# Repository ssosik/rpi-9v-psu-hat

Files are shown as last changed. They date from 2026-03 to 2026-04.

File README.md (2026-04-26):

# Raspberry Pi Preamp PSU HAT — Rev 3

A KiCad-designed Raspberry Pi HAT that generates a clean, isolated +9V supply from the Pi's 5V GPIO rail, intended to power low-noise electret microphone preamplifier circuits (such as the [ESP P93](https://sound-au.com/project93.htm)) for field audio recording applications like [BirdNET-Pi](https://github.com/mcguirepr89/BirdNET-Pi).

## Schematic

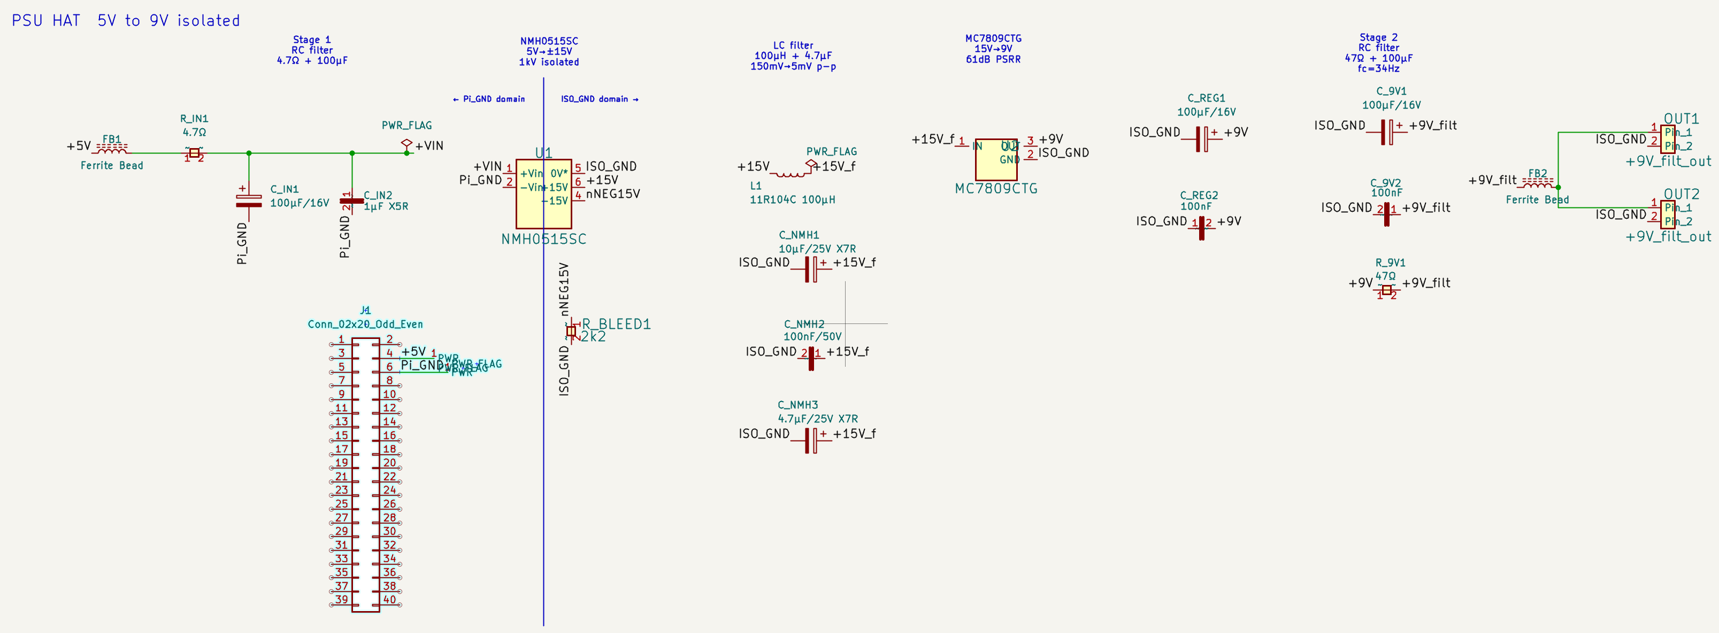
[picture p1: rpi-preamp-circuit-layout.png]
Schematic


## PCB Layout

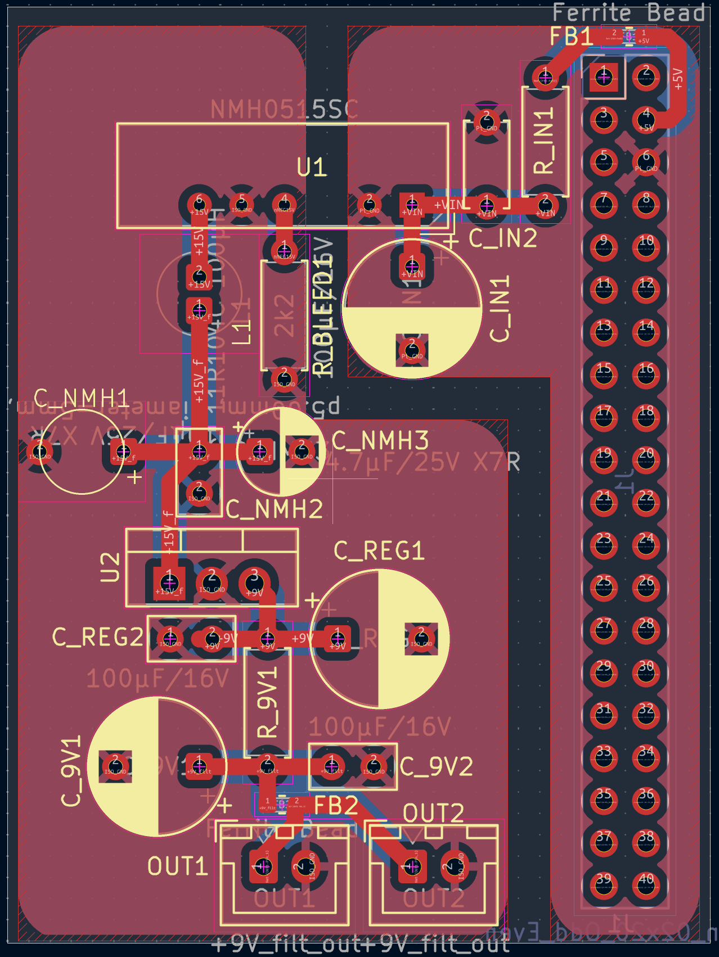
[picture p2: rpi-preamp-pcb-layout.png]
PCB Layout


## Overview

The Pi's 5V supply rail is noisy — unsuitable for sensitive microphone preamp circuits without significant filtering and regulation. This HAT addresses that with a multi-stage power supply chain:

1. **Stage 1 — Input filter**: Ferrite bead + capacitors attenuate high-frequency noise on the 5V input
2. **Isolated DC-DC conversion**: NMH0515SC converts 5V to ±15V with galvanic isolation, breaking any ground-loop path between the Pi and the preamp
3. **LC filter**: 100µH inductor + capacitors reduce switching noise from the DC-DC converter
4. **Linear regulation**: MC7809CTG drops the rectified +15V to a clean, regulated +9V
5. **Stage 2 — Output filter**: 47Ω series resistor + ferrite bead + multi-stage capacitor bank (100µF + 100nF) attenuates residual ripple before the output connectors

Two JST XH 2-pin output connectors (OUT1, OUT2) provide the filtered +9V, one per preamp channel.

## Key Components

| Designator | Part | Description |
|---|---|---|
| U1 | NMH0515SC | 5V → ±15V isolated DC-DC converter (Murata) |
| U2 | MC7809CTG | +9V linear regulator, TO-220 |
| L1 | 11R104C | 100µH radial inductor |
| FB1, FB2 | — | 0603 ferrite beads |
| J1 | 2×20 pin socket | Raspberry Pi GPIO header |
| OUT1, OUT2 | JST XH B2B | +9V filtered output connectors |

Full bill of materials: [`rpi-preamp-psu-hat-BoM.csv`](rpi-preamp-psu-hat-BoM.csv)

## Usage

### Hardware stack

```
[Raspberry Pi 4B]
      ↓ GPIO (5V + GND)
[This PSU HAT]
      ↓ JST XH (filtered +9V)
[P93 Stereo Preamp board]  ← electret capsules (EM272 or similar)
      ↓ balanced XLR
[HiFiBerry DAC+ ADC Pro]
      ↓ GPIO
[Raspberry Pi 4B]
```

### Stacking height

The HAT uses tall through-hole electrolytics (C_9V1, C_REG1: 100µF/16V, 8mm body). When stacking additional HATs, use an extra-tall stacking header to clear the tallest capacitors:

- **10mm stacking header** — [Adafruit #2223](https://www.adafruit.com/product/2223) (minimum clearance)
- **23mm stacking header** — [Adafruit #1979](https://www.adafruit.com/product/1979) (recommended)

Add M2.5 standoffs at the corner mounting holes for mechanical stability.

## Files

| File | Description |
|---|---|
| `rpi-preamp-psu-hat.kicad_sch` | KiCad schematic |
| `rpi-preamp-psu-hat.kicad_pcb` | KiCad PCB layout |
| `rpi-preamp-psu-hat.kicad_pro` | KiCad project file |
| `rpi-preamp-psu-hat-BoM.csv` | Bill of materials |
| `gerbers/` | Gerber files ready for fab |
| `gerbers.zip` | Gerber zip for direct upload to PCB fab |

## Fabrication Notes

- Board is designed for standard 2-layer FR4

## License

Released under [CERN Open Hardware Licence v2 – Strongly Reciprocal (CERN-OHL-S)](https://ohwr.org/cern_ohl_s_v2.txt). Derivatives must be released under the same license with design files made available.

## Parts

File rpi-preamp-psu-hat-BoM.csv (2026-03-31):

Id | Designator | Footprint | Quantity | Designation | Supplier and ref
1 | C_9V1, C_IN1, C_REG1 | CP_Radial_D8.0mm_P5.00mm | 3 | 100µF/16V
2 | C_9V2, C_REG2 | C_Disc_D5.0mm_W2.5mm_P2.50mm | 2 | 100nF
3 | C_IN2 | C_Disc_D5.0mm_W2.5mm_P5.00mm | 1 | 1µF X5R
4 | C_NMH1 | CP_Radial_D5.0mm_P5.00mm | 1 | 10µF/25V X7R
5 | C_NMH2 | C_Disc_D5.0mm_W2.5mm_P2.50mm | 1 | 100nF/50V
6 | C_NMH3 | CP_Radial_D5.0mm_P2.50mm | 1 | 4.7µF/25V X7R
7 | FB1, FB2 | L_0603_1608Metric_Pad1.05x0.95mm_HandSolder | 2 | Ferrite Bead
8 | J1 | PinSocket_2x20_P2.54mm_Vertical | 1 | Conn_02x20_Odd_Even
9 | L1 | L_Radial_D5.0mm_H7.5mm_P2.00mm | 1 | 11R104C 100µH
10 | OUT1, OUT2 | JST_XH_B2B-XH-A_1x02_P2.50mm_Vertical | 2 | +9V_filt_out
11 | R_9V1 | R_Axial_DIN0207_L6.3mm_D2.5mm_P7.62mm_Horizontal | 1 | 47Ω
12 | R_BLEED1 | R_Axial_DIN0207_L6.3mm_D2.5mm_P7.62mm_Horizontal | 1 | 2k2
13 | R_IN1 | R_Axial_DIN0207_L6.3mm_D2.5mm_P7.62mm_Horizontal | 1 | 4.7Ω
14 | U1 | Converter_DCDC_Murata_NMAxxxxSC_THT | 1 | NMH0515SC
15 | U2 | TO-220-3_Vertical | 1 | MC7809CTG

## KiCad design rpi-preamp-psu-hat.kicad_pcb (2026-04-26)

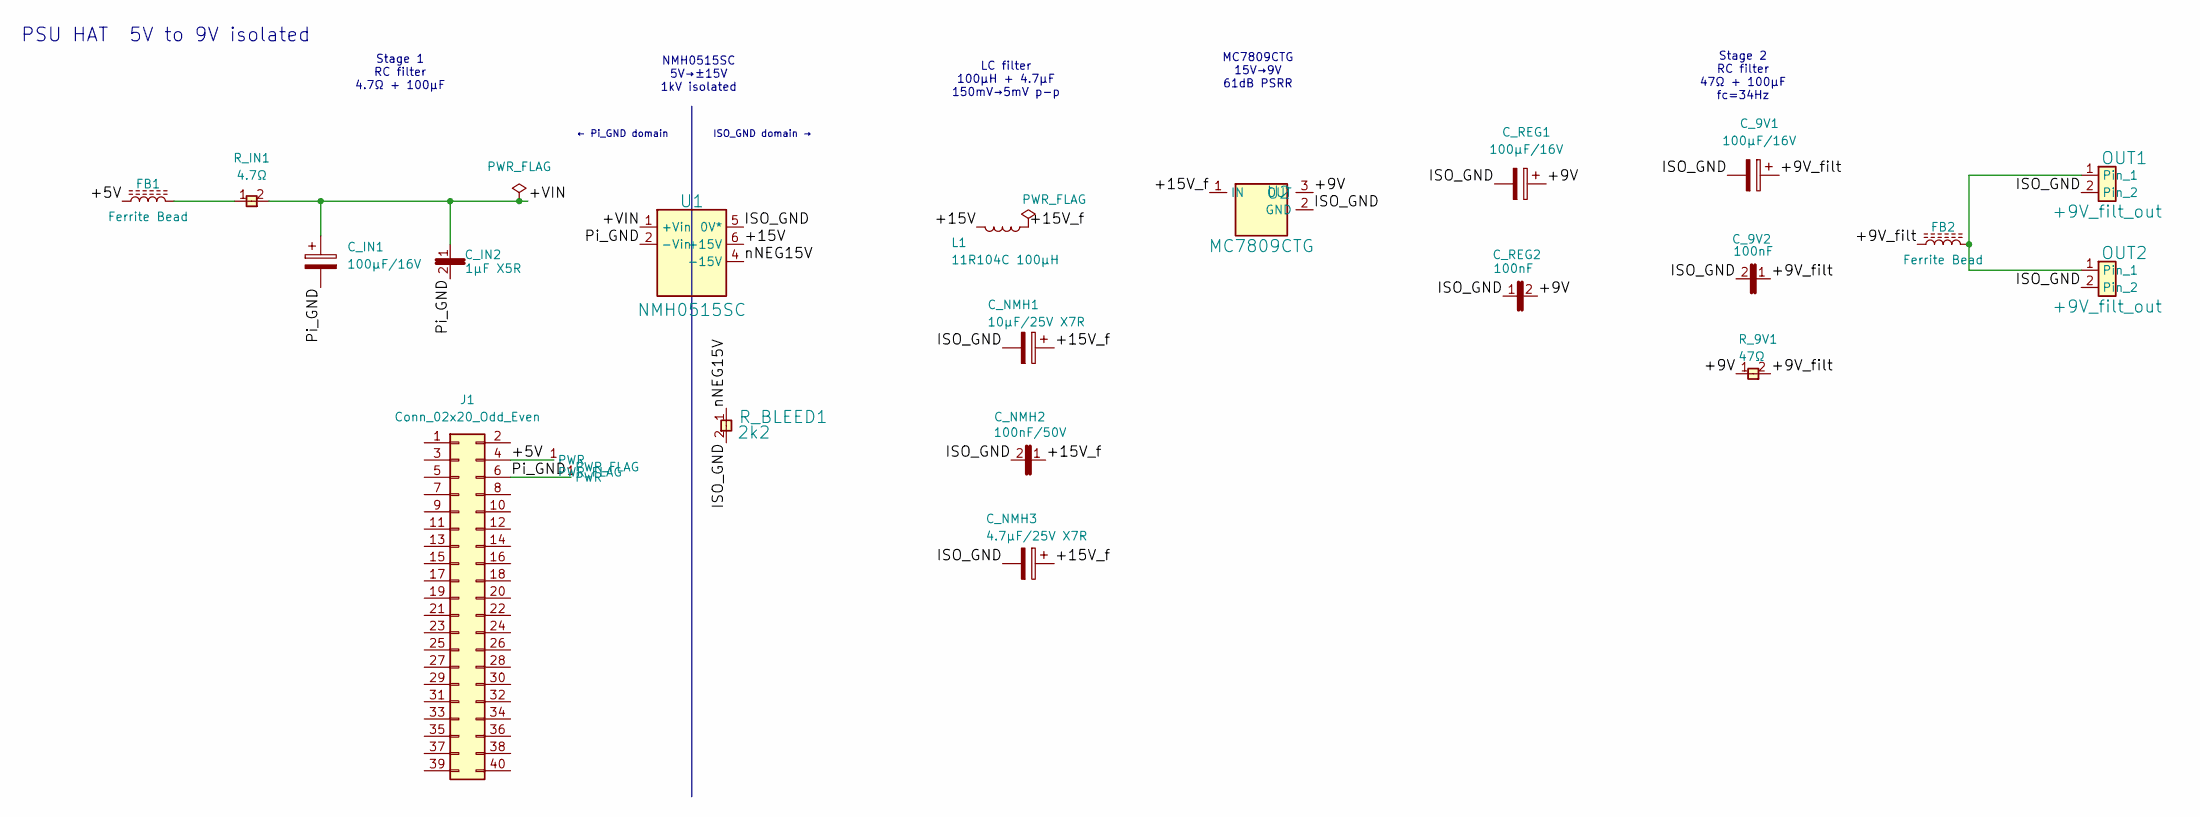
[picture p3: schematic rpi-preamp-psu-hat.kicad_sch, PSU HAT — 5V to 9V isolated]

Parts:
C_9V1: 100µF/16V; CP_Radial_D8.0mm_P5.00mm
C_9V2: 100nF; C_Disc_D5.0mm_W2.5mm_P2.50mm
C_IN1: 100µF/16V; CP_Radial_D8.0mm_P5.00mm
C_IN2: 1µF X5R; C_Disc_D5.0mm_W2.5mm_P5.00mm
C_NMH1: 10µF/25V X7R; CP_Radial_D5.0mm_P5.00mm
C_NMH2: 100nF/50V; C_Disc_D5.0mm_W2.5mm_P2.50mm
C_NMH3: 4.7µF/25V X7R; CP_Radial_D5.0mm_P2.50mm
C_REG1: 100µF/16V; CP_Radial_D8.0mm_P5.00mm
C_REG2: 100nF; C_Disc_D5.0mm_W2.5mm_P2.50mm
FB1, FB2: Ferrite Bead; L_0603_1608Metric_Pad1.05x0.95mm_HandSolder
J1: Conn_02x20_Odd_Even; PinSocket_2x20_P2.54mm_Vertical
L1: 11R104C 100µH; L_Radial_D5.0mm_H7.5mm_P2.00mm
OUT1, OUT2: +9V_filt_out; JST_XH_B2B-XH-A_1x02_P2.50mm_Vertical
R_9V1: 47Ω; R_Axial_DIN0207_L6.3mm_D2.5mm_P7.62mm_Horizontal
R_BLEED1: 2k2; R_Axial_DIN0207_L6.3mm_D2.5mm_P7.62mm_Horizontal
R_IN1: 4.7Ω; R_Axial_DIN0207_L6.3mm_D2.5mm_P7.62mm_Horizontal
U1: NMH0515SC; Converter_DCDC_Murata_NMAxxxxSC_THT
U2: MC7809CTG; TO-220-3_Vertical

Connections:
/+5V: FB1.1, J1.4
/+9V: C_REG1.1, C_REG2.2, R_9V1.1, U2.3 (OUT)
/+9V_filt: C_9V1.1, C_9V2.1, FB2.1, R_9V1.2
/+15V: L1.2, U1.6 (+15V)
/+15V_f: C_NMH1.1, C_NMH2.1, C_NMH3.1, L1.1, U2.1 (IN)
/+VIN: C_IN1.1, C_IN2.1, R_IN1.2, U1.1 (+Vin)
/ISO_GND: C_9V1.2, C_9V2.2, C_NMH1.2, C_NMH2.2, C_NMH3.2, C_REG1.2, C_REG2.1, OUT1.2, OUT2.2, R_BLEED1.2, U1.5 (0V*), U2.2 (GND)
/Pi_GND: C_IN1.2, C_IN2.2, J1.6, U1.2 (-Vin)
/nNEG15V: R_BLEED1.1, U1.4 (-15V)
unnamed: FB1.2, R_IN1.1
unnamed: FB2.2, OUT1.1, OUT2.1

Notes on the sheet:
Stage 1 RC filter 4.7Ω + 100µF
MC7809CTG 15V→9V 61dB PSRR
NMH0515SC 5V→±15V 1kV isolated
ISO_GND domain →
PSU HAT 5V to 9V isolated
← Pi_GND domain
LC filter 100µH + 4.7µF 150mV→5mV p-p
Stage 2 RC filter 47Ω + 100µF fc=34Hz

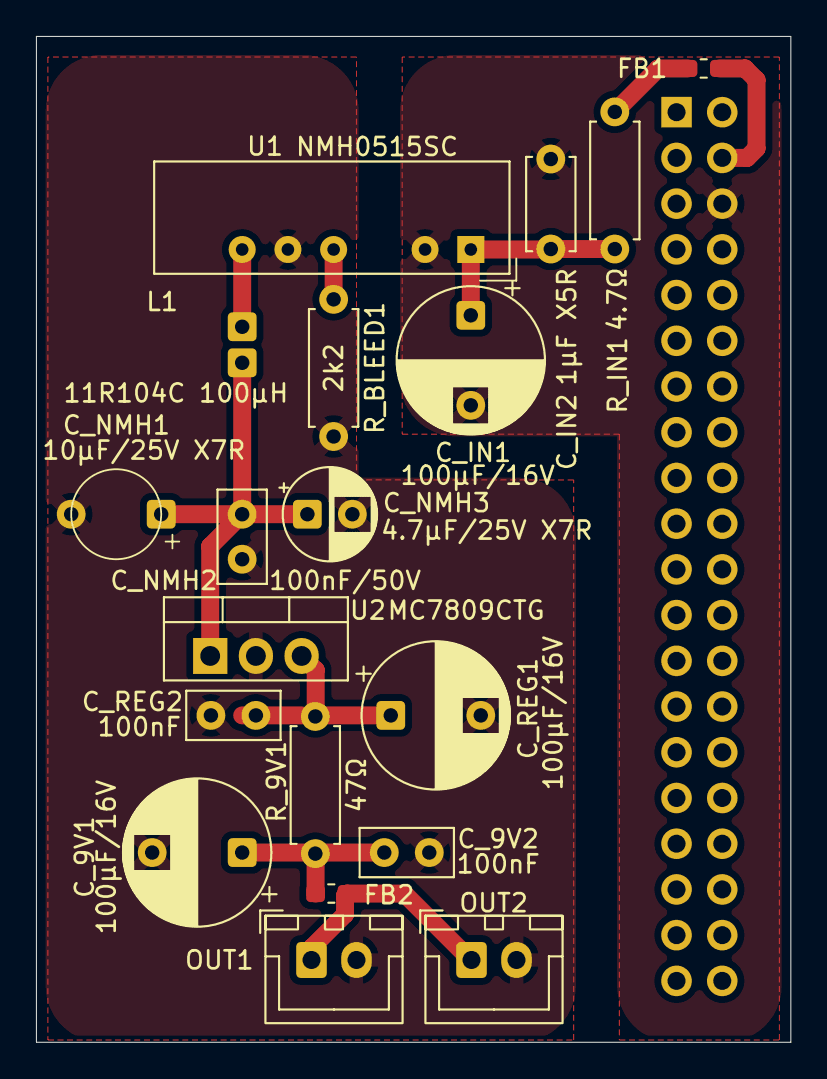
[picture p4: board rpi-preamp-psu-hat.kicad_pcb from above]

Board: 2 copper layers, 41.9 x 55.9 mm, 20 parts (1 on the bottom side), 11 nets.

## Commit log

2026-03-31 Initial add, good starting point
    [p93_hat_bom_v3.xlsx, rpi-preamp-psu-hat.kicad_pcb, rpi-preamp-psu-hat.kicad_sch]
2026-04-21 Cleanups for publishing
    [p93_hat_bom_v3.xlsx, rpi-preamp-psu-hat.kicad_sch]
2026-04-26 Add README and a PCB tweaks
    [rpi-preamp-psu-hat.kicad_pcb]
2026-06-13 Wire all J1 power/ground pins; clean up ERC
    - Schematic: J1 now ties both 5V pins and all 8 GND pins to +5V /
    Pi_GND. Previously only one of each was connected, concentrating
    return current through a single pin and leaving 7 GND pins floating.
    - Schematic: No-Connect markers on the 30 unused GPIO data pins.
    - PCB: route the new connections (DRC clean, schematic parity OK).
    - Register stereo-preamp-psu.pretty/ via fp-lib-table.
    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
2026-06-13 Fix FB1/FB2 footprint mismatch (BoM said 0603, PCB is 0805)
    The PCB and schematic both have 0805 footprints for the ferrite beads,
    but the BoM CSV and the symbol description text both referenced 0603
    (BLM18AG601). Boards are already fabricated with 0805 pads, so the
    PCB is authoritative.
    - BoM: 0603 footprint string -> 0805
    - Schematic: ferrite-bead description BLM18AG601 -> BLM21AG601
    (BLM21 is Murata's 0805 series; BLM18 is 0603)
    - PLAN.md: mark item 3 resolved
2026-06-13 R_BLEED1 2k2 -> 1k5 for NMH0515SC minimum-load margin
    The NMH0515SC datasheet (KDC_NMH.F03) specifies 10% minimum load per
    rail (6.7 mA at 67 mA rated). At 2k2, R_BLEED1 drew 6.82 mA -- right
    at the spec line with no tolerance margin. Worst-case resistor
    tolerance would dip below 10%, and the datasheet warns that sub-10%
    loading can cause the unloaded rail to rise (up to 2x at <5% load).
    1k5 draws 10 mA = ~15% of rated, comfortable margin. Dissipation
    150 mW, fits the existing DIN0207 footprint without PCB change.
2026-06-13 PLAN: close item 4 -- 7809 input decoupling verified on PCB
    Measured trace lengths on the +15V_f net from the input caps to
    U2 pin 1: C_NMH2 (100 nF) at 8.6 mm, C_NMH1 (10 uF) at 11.8 mm.
    Both well within the ~25 mm rule of thumb and inside the same
    copper path with no vias, so the regulator input is properly
    decoupled. No schematic/PCB change required.
2026-06-15 Rev 4: replace OUT2 JST with center-negative 2.1mm barrel jack
    Schematic-only change; PCB layout work still pending in KiCad GUI.
    - Add Connector:Barrel_Jack to lib_symbols cache (copied verbatim
    from KiCad stock Connector library)
    - Swap OUT2 instance: Conn_01x02_Pin -> Barrel_Jack, position shifted
    to (313.69, 52.07) so pin 2 (tip) lands on the existing ISO_GND
    label at (321.31, 54.61)
    - Footprint -> Connector_BarrelJack:BarrelJack_CUI_PJ-102AH_Horizontal
    (PJ-102AH style, 2.1mm x 5.5mm horizontal/edge-mount)
    - Re-anchor +9V_filt distribution wires to new pin 1 (321.31, 49.53)
    - Center-negative wiring (pedalboard convention): pin 1/sleeve = +9V,
    pin 2/tip = ISO_GND
    PLAN.md gets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
2026-06-15 Rev 4 PCB: sync barrel jack, add HAT mounting holes, expand outline
    - OUT2 footprint synced to BarrelJack_CUI_PJ-102AH_Horizontal at
    (134.112, 91.59), 0deg rotation. Jack opens toward the bottom board
    edge (Y~=105.5) with the metal barrel protruding past Edge.Cuts
    (Y=106.27). Pin 1 (sleeve) on +9V_filt_out, pin 2 (tip) on ISO_GND.
    - Add two non-plated MountingHole_2.7mm_M2.5_DIN965 at
    (153.365, 45.161) and (153.314, 103.175), matching PLAN R4-B
    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
2026-06-16 PLAN: reflect current state after R4-A/R4-B PCB sync
    - Item 0: mark done; PCB sync landed in bf55525 (J1 power/ground pins
    wired with F.Cu point-to-point). Keep the copper-pour idea as a
    deferred sub-task with a U1-isolation-line keep-out reminder.
    - R4-A: mark done (schematic in d4713eb, PCB in d1d199c). Record the
    actual barrel jack placement (134.112, 91.59, 0deg, opening at +Y
    near board edge Y=106.27) and flag the +9V_filt_out label not
    binding to the post-FB2 wire (PCB shows Net-(OUT1-Pin_1) instead).
    - R4-B: mark done (d1d199c). Record actual mounting hole coords and
    the realized Edge.Cuts (~42.2 x 64.3 mm). Note tight edge clearances
    to watch on next DRC.
    - Rewrite Next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
2026-06-16 Nudge OUT1 0.65mm; refresh ERC/DRC reports
    - OUT1 (JST) moved from (124.5616, 92.456) to (124.1044, 92.9132) and
    the +9V_filt_out trace re-routed to the new pin 1 location. Slight
    increase in clearance to the OUT2 barrel jack body.
    - Regenerate ERC and DRC reports against the current rev-4 board:
    ERC unchanged at 14 warnings (library drift only). DRC down to 39
    (was 42); old JST OUT2 silk warnings gone, FB1-over-J1-pads cleared.
    New warnings worth following up: silk_edge_clearance on the top
    mounting hole's REF** text (sits 0.15mm outside the new top edge),
    and silk_overlap between OUT1 ref and OUT2 silk.
    - Track the .rpt files starting from this commit so future reviewers
    ca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
2026-06-16 R4-B: mounting holes to header centerline X, keep symmetric Y offsets
    User feedback: the holes need to be inline with the 2x20 header and
    sit symmetrically around it, not asymmetrically per my over-literal
    read of the HAT mechanical drawing "29" dimension.
    PCB changes:
    - Hole near J1 pin 1: (153.3652, 45.1612) -> (151.13, 45.185).
    X moves to GPIO header centerline; Y stays at the original
    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
2026-06-17 Regenerate BoM, ERC, and DRC artifacts
    - BoM now generated via kicad-cli sch export bom, grouped by
    Value+Footprint with semicolon delimiter to match prior format.
    OUT2 correctly split out from OUT1 with the new barrel jack
    footprint (Connector_BarrelJack:BarrelJack_CUI_PJ-102AH_Horizontal,
    value Barrel_Jack_2.1mm_CN). Resistors (R_9V1, R_BLEED1, R_IN1)
    show the DIN0204 vertical footprint that's actually assigned in the
    schematic, replacing the stale DIN0207 horizontal entries in the
    old hand-maintained CSV. DIN0204 vertical is the intended part.
    - DRC: 38 violations (down from 42). All remaining are cosmetic /
    library: 33 text_height, 2 silk_overlap, 2 silk_over_copper, 1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
2026-10-30 Rev 4 final review: fix net/lib/polarity docs, add logo, regen fab outputs
    - Add +9V_filt_out label; rename PCB net from Net-(OUT1-Pin_1)
    - OUT2 value CN -> CP to match actual center-positive wiring; CTR+ silk
    - Widen Pi_GND/ISO_GND pour channel to 2.54 mm everywhere (was 1.905)
    - Fix fp-lib-table nickname and point at ${KIPRJMOD}
    - Add sosik logo footprint + Rev 4 silk; MH1/MH2 board_only
    - Remove empty Untitled.kicad_mod
    - Regenerate gerbers/drill/zip, ERC/DRC reports, README images
    - Update README, PLAN (R4-C + open TODOs), CLAUDE.md; add .gitignore
